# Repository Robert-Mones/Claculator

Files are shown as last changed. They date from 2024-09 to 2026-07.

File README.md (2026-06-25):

# Claculator
A reverse Polish notation calculator with added features such as comparisons, branching, and custom recursive operators taken from the Clac project from the 15-122 course at Carnegie Mellon University. The project is built around a 65C02 microprocessor with a custom architecture to reduce CPU load by making memory-mapped peripherals operate asynchronously. All logic and board design was done in KiCAD. All 3D modeling was done in Autodesk Fusion.

<p align="center">Fully assembled Claculator</p>

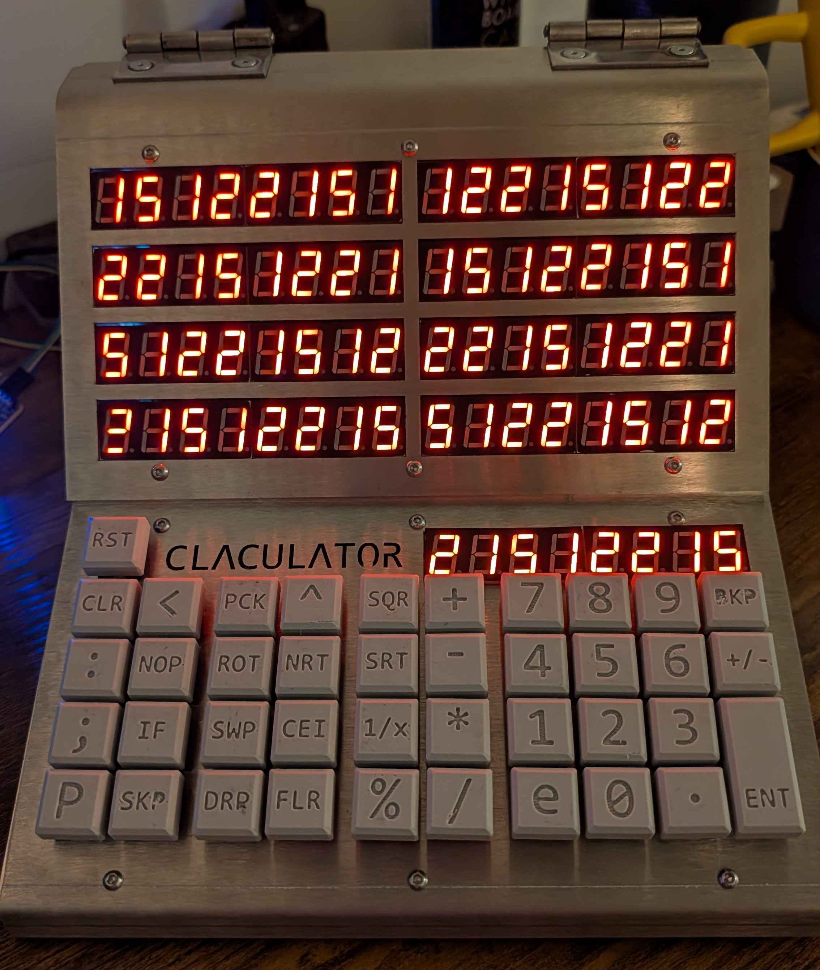
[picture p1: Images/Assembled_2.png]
Fully assembled Claculator


## Display
The seven-segment display board supports nine numeric displays, each with eight digits. It contains an SRAM chip which interfaces to the rest of the computer as a memory-mapped peripheral. When selected, the address and data bus is connected to the computer to be written to (but not read from) transparently. When the memory is not selected, a counter with a selectable clock source loops through each of the seventy-two digits, reads the corresponding byte from memory, and drives the corresponding digit using one bit for each segement (seven for the numeric part, one for the decimal point) with an array of P- and N-channel MOSFETs.

<p align="center">The front of the display, showing eight numeric displays</p>

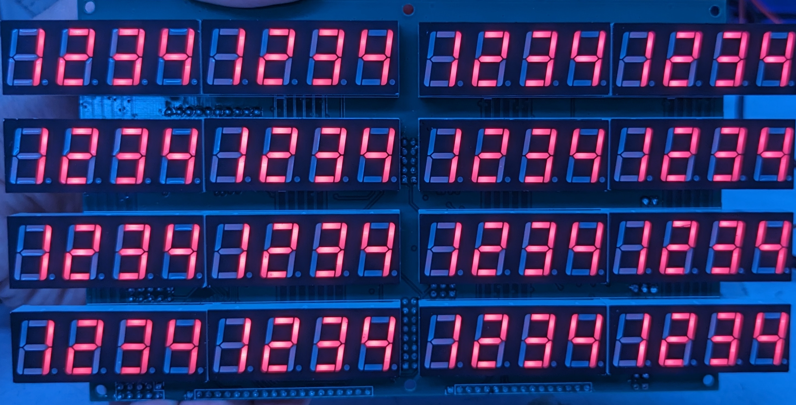
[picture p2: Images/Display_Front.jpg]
The front of the display, showing eight numeric displays


<p align="center">The back of the display, showing the logic and driver chips</p>

The back of the display, showing the logic and driver chips

## Keypad
The keypad input board supports up to sixteen rows (5 are implemented), each with eight buttons. It detects rising edges of each button (equivalent to KeyDown events) with hardware RC debouncing and writes this information to a hardware FIFO buffer which is interfaced directly to the address and data bus of the system and can be configured to send an interrupt on new information in the buffer. It also has a header and location for a seven-segment display (not populated in these photos) as the ninth display that is driven from the display board.

<p align="center">The front of the keypad, showing five groups of eight keys</p>

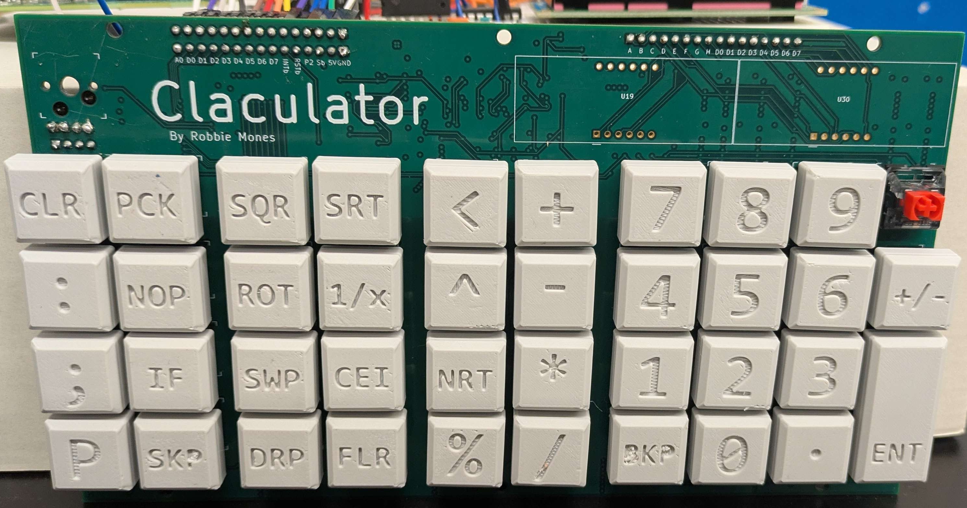
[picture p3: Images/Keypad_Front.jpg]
The front of the keypad, showing five groups of eight keys


<p align="center">The back of the keypad, showing the logic chips and hot-swappable key sockets</p>

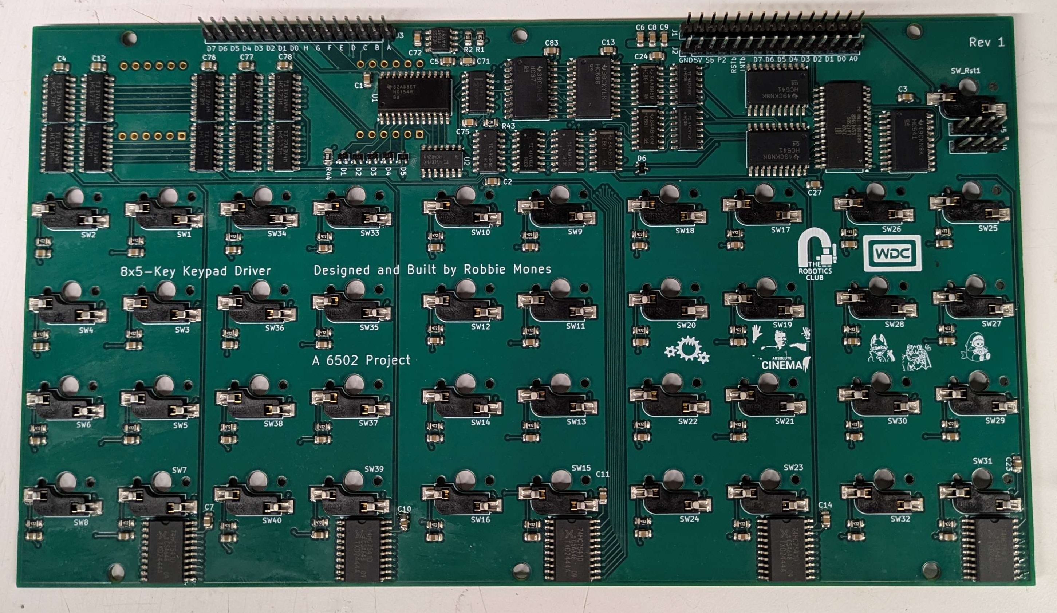
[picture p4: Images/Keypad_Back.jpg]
The back of the keypad, showing the logic chips and hot-swappable key sockets


## Chassis
The chassis for the Claculator was manufactured by SendCutSend out of 1/8"-thick 304 stainless steel (except for the keypad plate which must be 0.06" thick to fit the keys). It has hinges at the top back to open the Claculator from the front to enable demonstrations and debugging more easily. It is very heavy (8lbs of sheet metal) and was very expensive but it's worth it for the bit.

<p align="center">Model of the assembled Claculator</p>

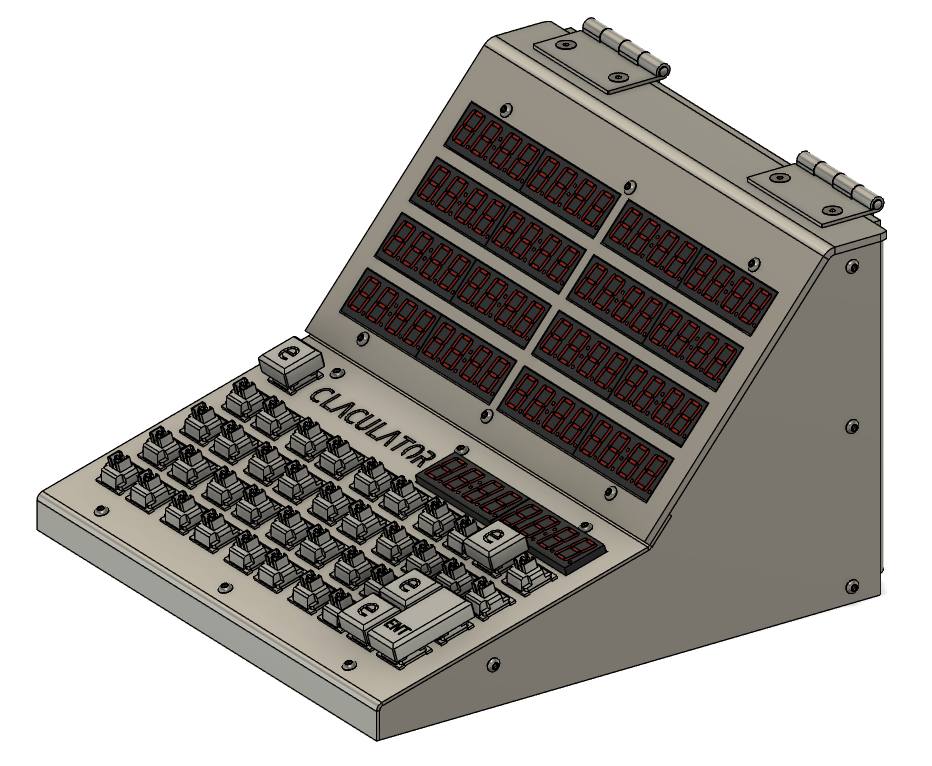
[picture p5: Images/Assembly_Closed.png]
Model of the assembled Claculator


## Code
I am currently working on some tests building up to a 32-bit integer mode to develop the RPN behavior and a feature-complete Clac implementation. After this, I will write a software 32-bit floating point implementation to support decimal arithmetic and comparisons. All of the code for this project will be written in 65C02 assembly.

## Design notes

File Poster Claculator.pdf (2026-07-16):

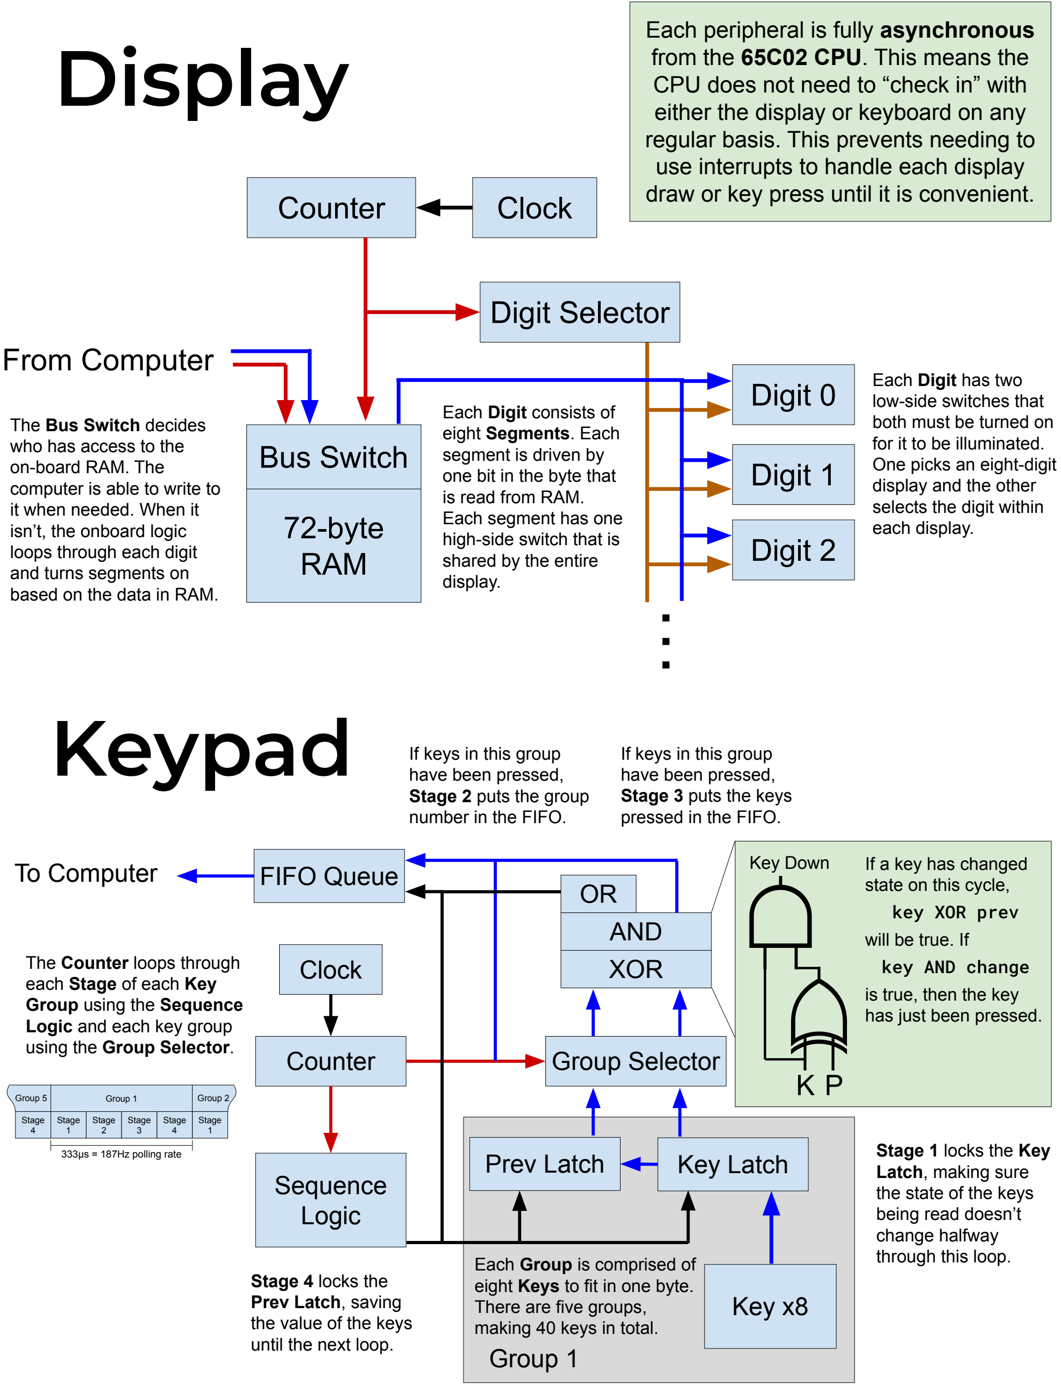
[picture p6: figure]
Display; Keypad; 72-byte RAM; Counter; Digit 0; Digit 1; Digit 2; Digit Selector; From Computer; Bus Switch; Clock; The Bus Switch decides who has access to the on-board RAM. The computer is able to write to it when needed. When it isn’t, the onboard logic loops through each digit and turns segments on based on the data in RAM.; Each Digit consists of eight Segments. Each segment is driven by one bit in the byte that is read from RAM. Each segment has one high-side switch that is shared by the entire display.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

…

draw or key press until it is convenient.

https://github.com/Robert-Mones/Claculator

## Group 2

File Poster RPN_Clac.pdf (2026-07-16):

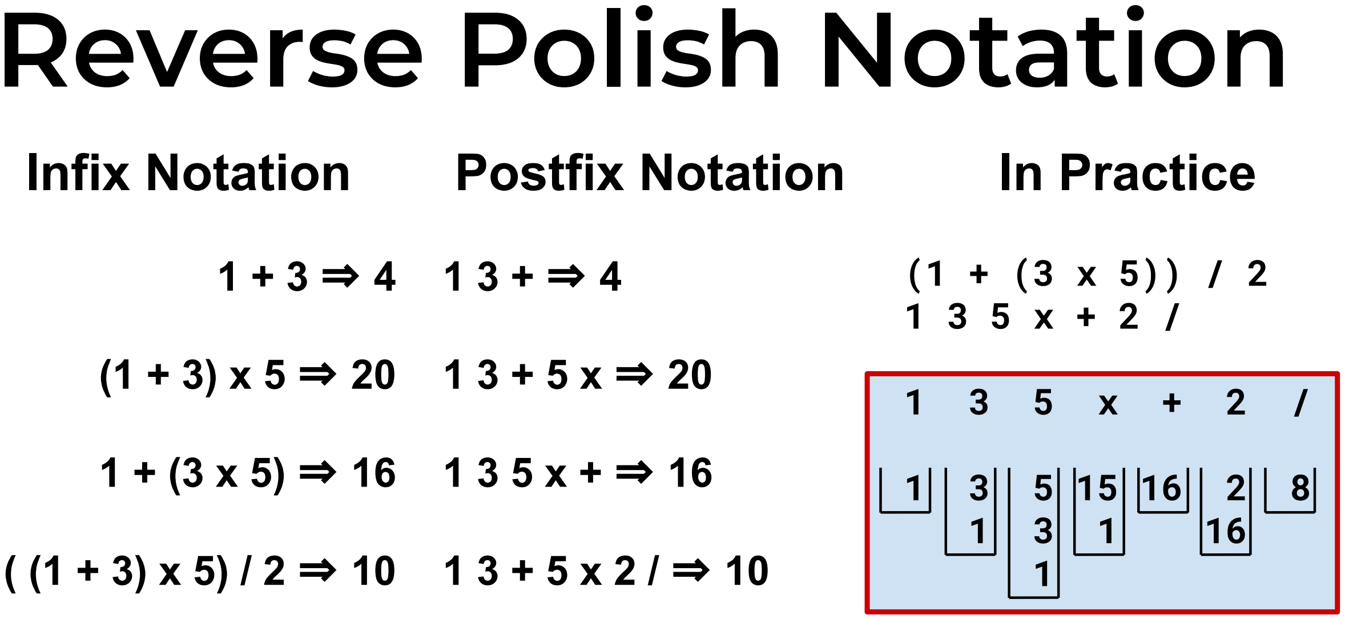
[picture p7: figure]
Reverse Polish Notation; Infix Notation; Postfix Notation; In Practice

Operators take the top two elements off of the stack, operate on them, and put
the result back on the stack.

Reverse Polish Notation uses a Stack to process each expression left-to-right.

Each symbol is either an operand (number) or an operator (+, -, x, etc).

Operands are pushed to the stack.

# Clac

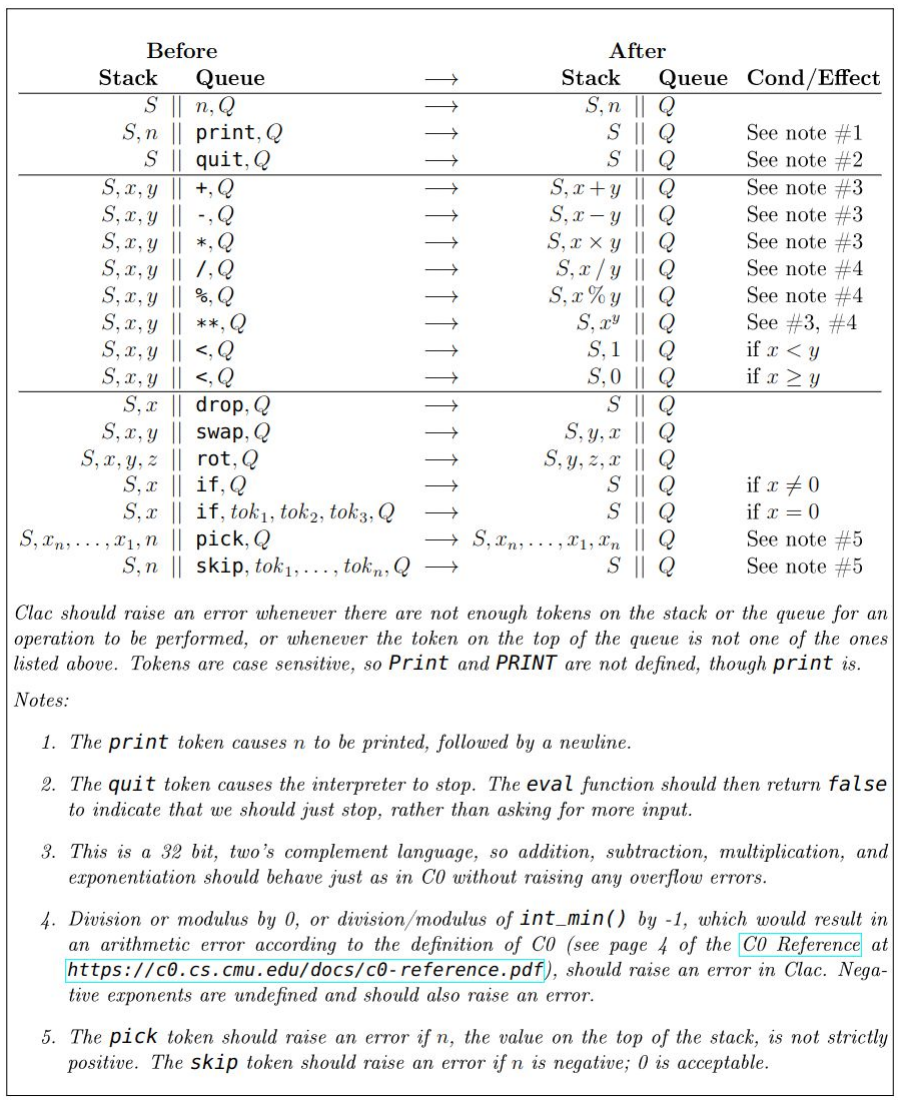
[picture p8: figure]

Complete Clac reference reproduced with permission
Clac is an extension to RPN similar to the Forth programming language which adds additional operators like if and skip, as well as custom operators which can be recursive.
This allows “programs” to be written in Clac which are able to perform complex mathematical calculations. It’s actually Turing-complete!

The following implements a Fibonacci using the Clac operators. : fib dup 2 < if nop 9 skip 1 - dup 1 - fib swap fib + ;

Pseudocode:
fib(x):
if x < 2:
return x
return fib(x-2) + fib(x-1)

1 3 +

1 | 3 | 4
| 1

# No parentheses!

# Easy to evaluate!

# Turing-complete*!

*Clac extension sold separately

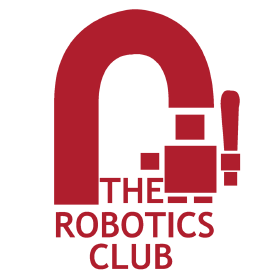
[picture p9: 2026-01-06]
Claculator_Keypad/Imagery/Roboclub.png

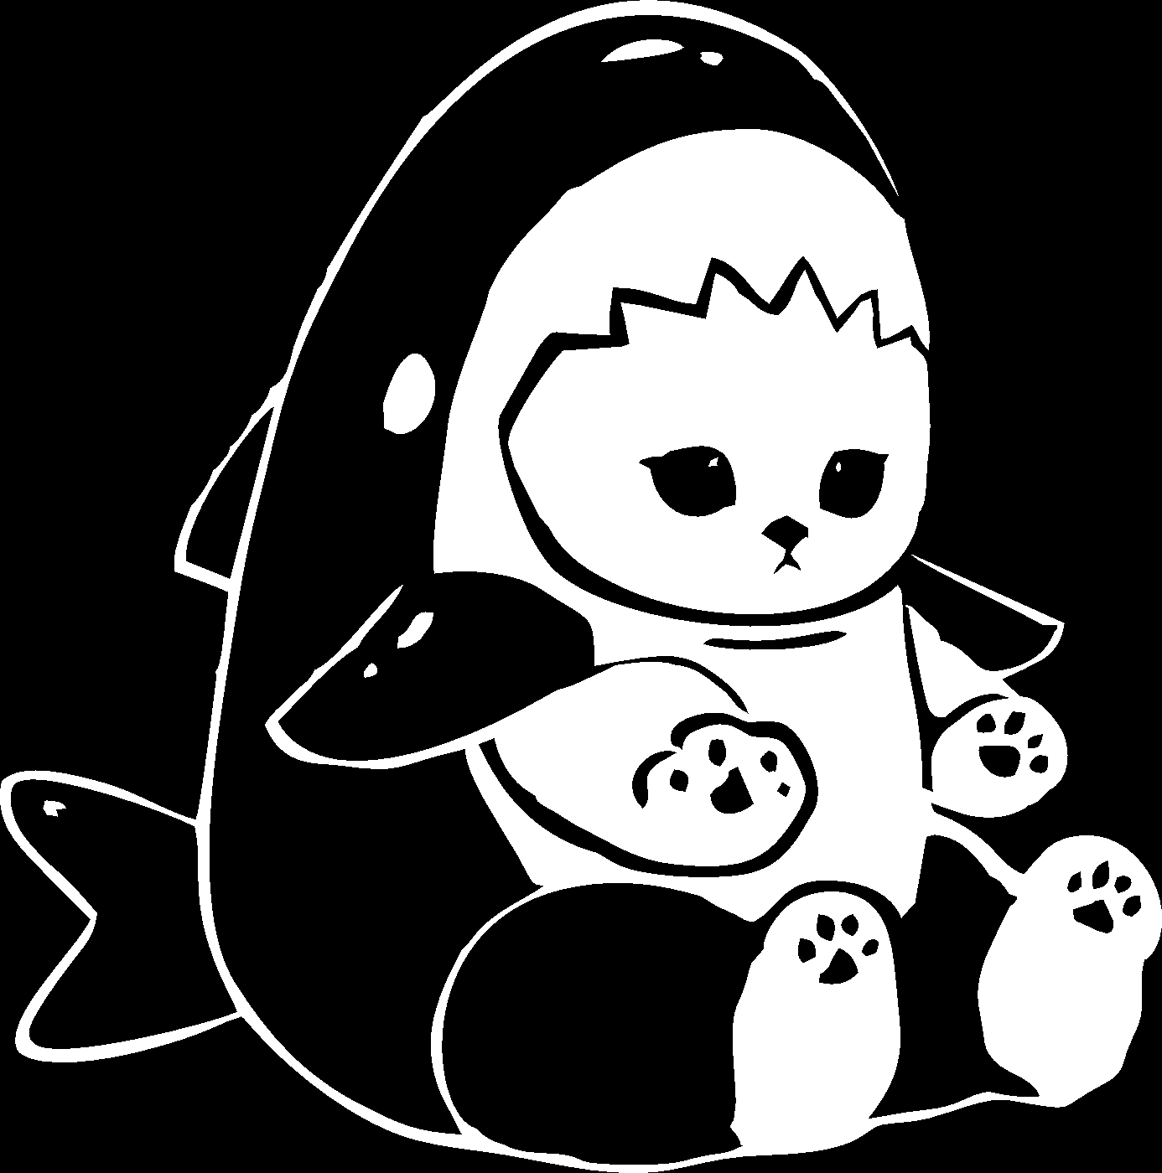
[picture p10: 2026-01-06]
Claculator_Display/Imagery/bnyahaj.png

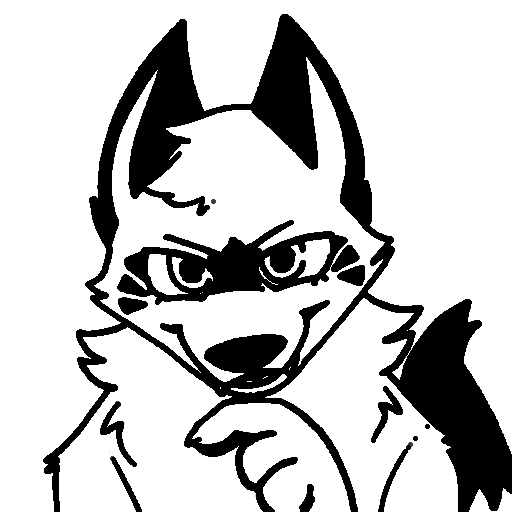
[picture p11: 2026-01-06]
Claculator_Keypad/Imagery/salixplotting-thick.png

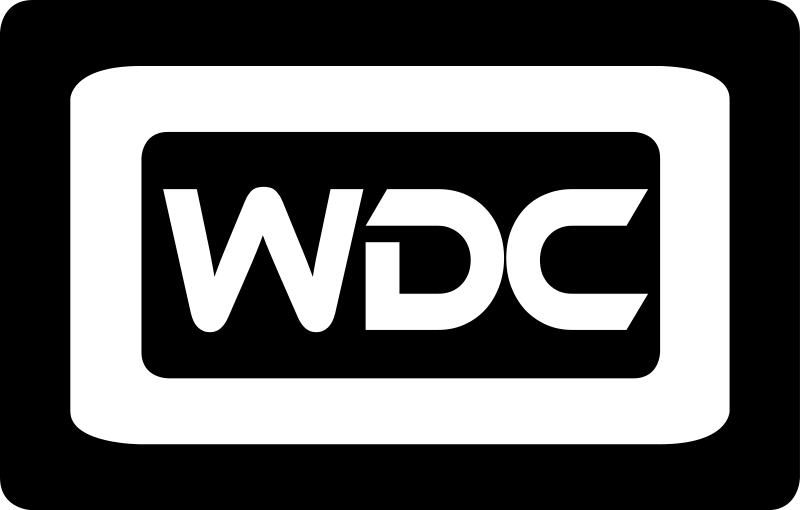
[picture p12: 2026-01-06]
Claculator_Keypad/Imagery/WDC.png

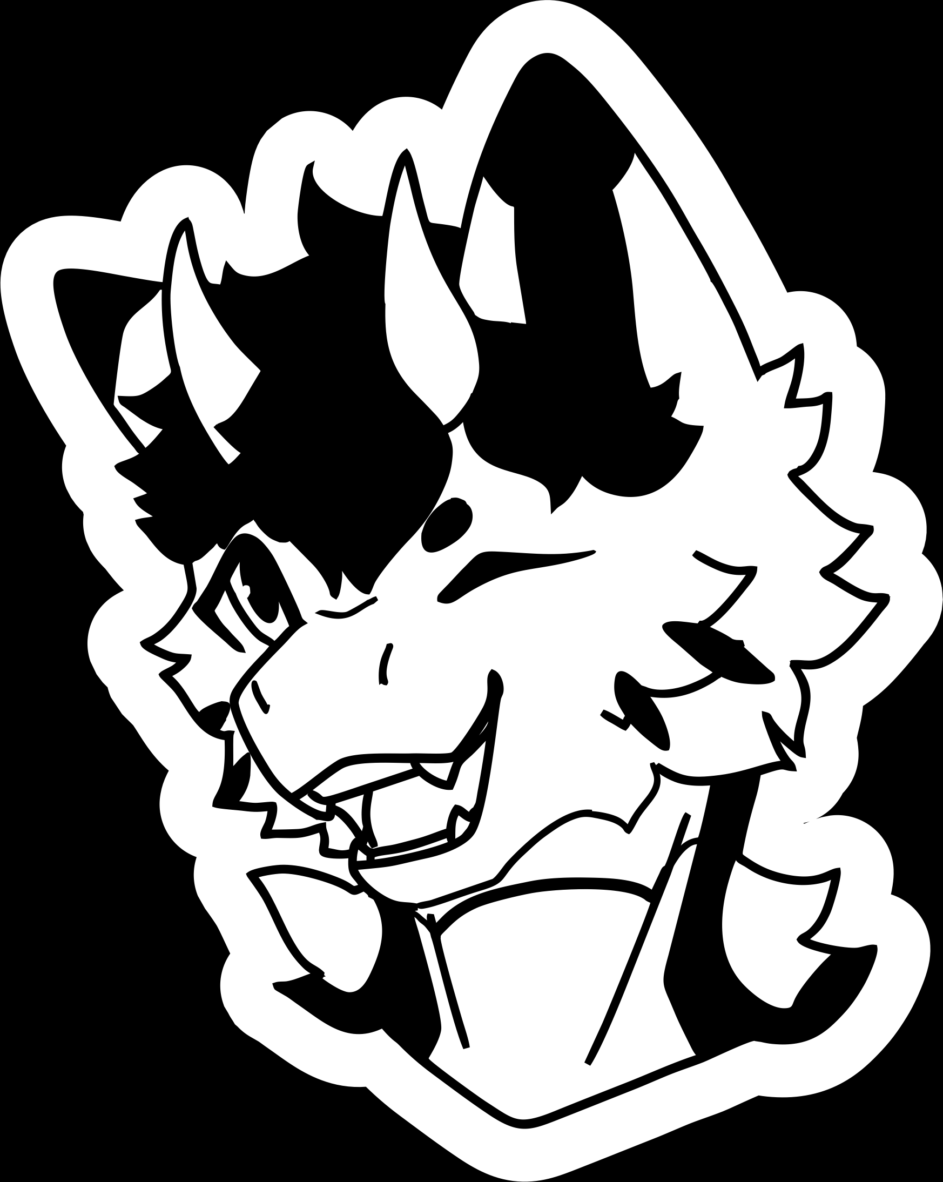
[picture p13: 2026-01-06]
Claculator_Display/Imagery/sky.png

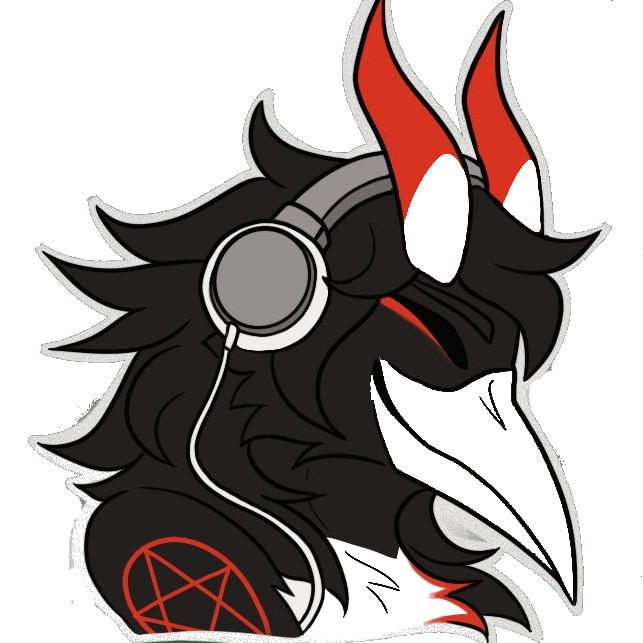
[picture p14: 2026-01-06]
Claculator_Display/Imagery/dante.png

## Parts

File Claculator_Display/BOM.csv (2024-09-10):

Reference | Value | Datasheet | Footprint | Qty | DNP
C1,C4 | 10uF | ~ | Capacitor_SMD:C_1206_3216Metric | 2
C2,C5,C7,C8,C9,C10,C11,C12,C13,C14,C15,C16,C17,C18,C19,C20,C21,C22,C23 | 1uF | ~ | Capacitor_SMD:C_1206_3216Metric | 19
C3,C6 | 0.1uF | ~ | Capacitor_SMD:C_1206_3216Metric | 2
C24,C25 | 100uF | ~ | Capacitor_SMD:CP_Elec_5x3 | 2
J1,U14,U15,U16,U17,U34,U35,U36 | ~ |  | -- mixed values -- | 8
J4 | Conn_01x20_Pin | ~ | Connector_PinHeader_2.54mm:PinHeader_1x20_P2.54mm_Vertical | 1
J5 | Power Input | ~ | Connector:JWT_A3963_1x02_P3.96mm_Vertical | 1
J6 | Conn_01x16_Pin | ~ | Connector_PinHeader_2.54mm:PinHeader_1x16_P2.54mm_Vertical | 1
Q1,Q2,Q3,Q4,Q5,Q6,Q7,Q8 | PMOS | https://ngspice.sourceforge.io/docs/ngspice-manual.pdf | Custom_Library:SOT-23P | 8
Q9,Q10,Q11,Q12,Q13,Q14,Q15,Q16,Q17,Q18,Q19,Q20,Q21,Q22,Q23,Q24,Q25,Q26,Q27,Q28,Q29,Q30,Q31,Q32,Q33,Q34,Q35,Q36,Q37,Q38,Q39,Q40,Q41,Q42,Q43,Q44,Q45,Q46,Q47,Q48,Q49,Q50,Q51,Q52,Q53,Q54,Q55,Q56,Q57,Q58,Q59,Q60,Q61,Q62,Q63,Q64,Q65,Q66,Q67,Q68,Q69,Q70,Q71,Q72,Q73,Q74,Q75,Q76,Q77,Q78,Q79,Q80,Q81,Q82,Q83,Q84,Q85,Q86,Q87,Q88,Q89 | NMOS | https://ngspice.sourceforge.io/docs/ngspice-manual.pdf | Custom_Library:SOT-23N | 81
R1 | 10K | ~ | Resistor_SMD:R_1206_3216Metric | 1
U1,U2,U6 | 74HC541 | http://www.ti.com/lit/gpn/sn74HCT541 | Package_SO:SOIC-20W_7.5x12.8mm_P1.27mm | 3
U3 | 74HC14 | http://www.ti.com/lit/gpn/sn74HC14 | Package_SO:SOIC-14_3.9x8.7mm_P1.27mm | 1
U4 | 74HC00 | http://www.ti.com/lit/gpn/sn74hc00 | Package_SO:SOIC-14_3.9x8.7mm_P1.27mm | 1
U5 | IS62C256AL | https://www.futurlec.com/Datasheet/Memory/62256.pdf | IS62C256AL_45ULI_TR:SOIC127P1210X305-28N | 1
U7 | 74HC4020 | http://www.intersil.com/content/dam/Intersil/documents/cd40/cd4020bms-24bms-40bms.pdf | Package_SO:SOIC-16_3.9x9.9mm_P1.27mm | 1
U8 | 74HC4024 | https://assets.nexperia.com/documents/data-sheet/74HC4024.pdf | Package_SO:SOIC-14_3.9x8.7mm_P1.27mm | 1
U9,U10 | 74HC154 |  | Package_SO:SOIC-24W_7.5x15.4mm_P1.27mm | 2
U11 | LD1086V33-DG | https://www.st.com/resource/en/datasheet/ld1086.pdf | Package_TO_SOT_THT:TO-220-3_Vertical | 1
U12,U13,U18,U19,U20,U21,U22,U23,U24,U25,U26,U27,U28,U29,U30,U31 | CC56-12EWA | http://www.kingbrightusa.com/images/catalog/SPEC/CA56-12EWA.pdf | Display_7Segment:CA56-12EWA | 16

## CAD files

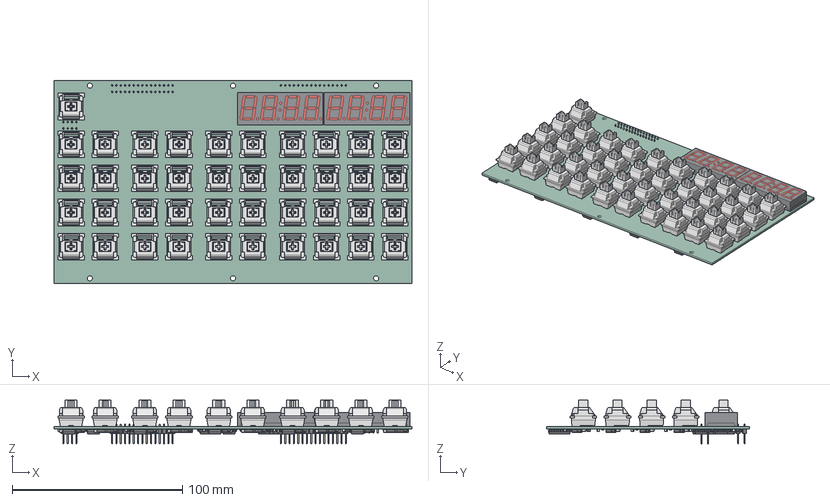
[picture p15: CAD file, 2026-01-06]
Claculator_Keypad/Claculator_Keypad.step
210.0 x 119.0 x 25.5 mm
REDragon-MX-ZT02 x 41
Kailh Hotswap MX v22 x 41
Body_sp x 2
C_0805_2012Metric x 64
R_0805_2012Metric x 44
SOIC_16_39x99mm_P127mm x 10
SOT_323_SC_70 x 6
SOIC_20W_75x128mm_P127mm x 10
SOIC_14_39x87mm_P127mm x 10
PinHeader_1x16_P254mm_Vertical
SOIC_28W_75x187mm_P127mm
SOIC_8_39x49mm_P127mm
SOIC_24W_75x154mm_P127mm
PinHeader_1x04_P254mm_Vertical x 2
PinHeader_1x15_P254mm_Vertical x 2
Claculator_Keypad_PCB

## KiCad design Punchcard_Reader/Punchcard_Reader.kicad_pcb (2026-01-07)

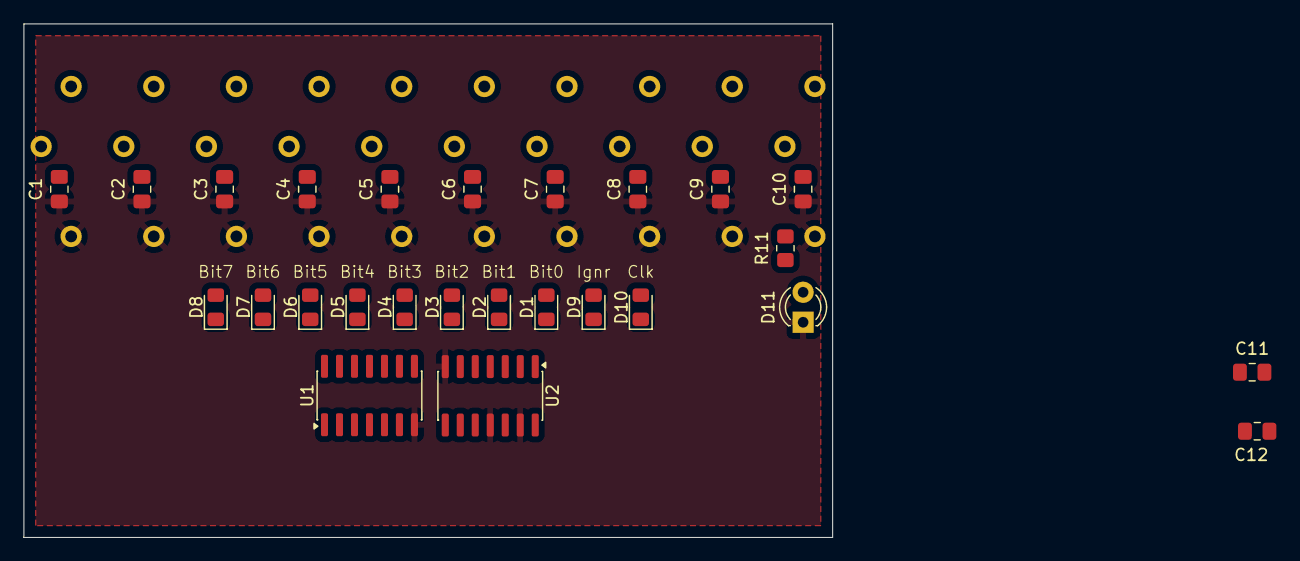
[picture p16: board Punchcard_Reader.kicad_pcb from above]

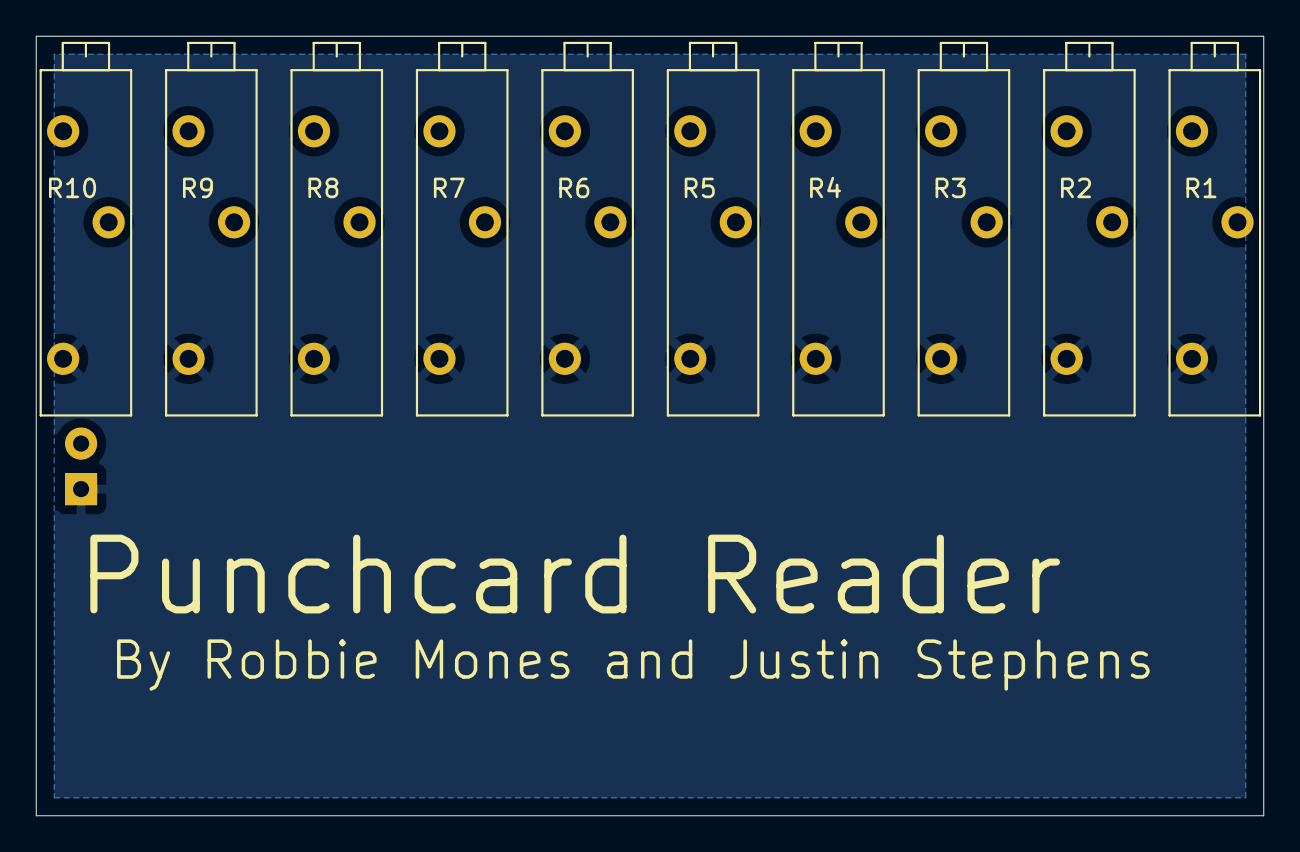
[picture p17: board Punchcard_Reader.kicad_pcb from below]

Board: 4 copper layers, 68.5 x 43.5 mm, 36 parts (10 on the bottom side), 13 nets, no tracks yet.

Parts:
C1, C2, C3, C4, C5, C6, C7, C8, C9, C10: 470pF; C_0805_2012Metric_Pad1.18x1.45mm_HandSolder
C11, C12: 0.1uF; C_0805_2012Metric_Pad1.18x1.45mm_HandSolder
D1, D2, D3, D4, D5, D6, D7, D8, D9, D10: APS2012SP1C; LED_0805_2012Metric_Pad1.15x1.40mm_HandSolder
D11: LED_BACKLIGHT; LED_D3.0mm
R1, R2, R3, R4, R5, R6, R7, R8, R9, R10: 500k; VariableResistor_Bourns_3006P_Horizontal_
R11: 120Ω; R_0805_2012Metric_Pad1.20x1.40mm_HandSolder
U1, U2: 74HC14; SOIC-14_3.9x8.7mm_P1.27mm

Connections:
+5V: C11.1, C12.1, D1.1 (K), D2.1 (K), D3.1 (K), D4.1 (K), D5.1 (K), D6.1 (K), D7.1 (K), D8.1 (K), D9.1 (K), D10.1 (K), R11.1, U1.14 (VCC), U2.14 (VCC)
GND: C1.2, C2.2, C3.2, C4.2, C5.2, C6.2, C7.2, C8.2, C9.2, C10.2, C11.2, C12.2, D11.1 (K), R1.1, R2.1, R3.1, R4.1, R5.1, R6.1, R7.1, R8.1, R9.1, R10.1, U1.7 (GND), U2.7 (GND), U2.11, U2.13
unnamed: C1.1, D1.2 (A), R1.2, U1.1
unnamed: C2.1, D2.2 (A), R2.2, U1.3
unnamed: C3.1, D3.2 (A), R3.2, U1.5
unnamed: C4.1, D4.2 (A), R4.2, U1.9
unnamed: C5.1, D5.2 (A), R5.2, U1.11
unnamed: C6.1, D6.2 (A), R6.2, U1.13
unnamed: C7.1, D7.2 (A), R7.2, U2.1
unnamed: C8.1, D8.2 (A), R8.2, U2.3
unnamed: C9.1, D9.2 (A), R9.2, U2.5
unnamed: C10.1, D10.2 (A), R10.2, U2.9
unnamed: D11.2 (A), R11.2

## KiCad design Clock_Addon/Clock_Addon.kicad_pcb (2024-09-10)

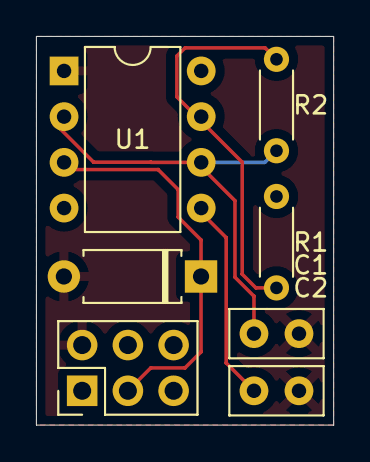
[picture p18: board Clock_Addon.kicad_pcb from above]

Board: 6 copper layers, 16.5 x 21.6 mm, 7 parts (0 on the bottom side), 6 nets.

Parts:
C1, C2: C; C_Disc_D5.0mm_W2.5mm_P2.50mm
D1: D_Zener; D_A-405_P7.62mm_Horizontal
J2: Conn_01x06_Pin; PinHeader_2x03_P2.54mm_Vertical
R1, R2: R; R_Axial_DIN0204_L3.6mm_D1.6mm_P5.08mm_Horizontal
U1: NE555P; DIP-8_W7.62mm

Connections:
+5V: J2.1, R1.1, U1.4 (R), U1.8 (VCC)
CNTR_CLK: D1.1 (K), J2.3, U1.3 (Q)
GND: C1.2, C2.1, D1.2 (A), J2.2, U1.1 (GND)
unnamed: C2.2, U1.5 (CV)
unnamed: R1.2, R2.1, U1.7 (DIS)
unnamed: C1.1, R2.2, U1.2 (TR), U1.6 (THR)

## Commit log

2024-09-10 Added existing KiCAD projects
    [BOM.csv, BOM_Final.csv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]
2026-01-06 Added kicad backups to gitignore
2026-01-06 Added Clock_Addon kicad backups to gitignore
2026-01-06 Not sure
    [Claculator_Keypad-B_Cu.gbl, Claculator_Keypad-B_Mask.gbs, Claculator_Keypad-B_Paste.gbp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]
2026-01-06 Added Punchcard_Reader kicad backups and lock files to gitignore
2026-01-06 Punchcard_Reader init commit
    [Punchcard_Reader.kicad_pcb, Punchcard_Reader.kicad_sch]
2026-01-07 Added initial parts
    [Punchcard_Reader.kicad_pcb, Punchcard_Reader.kicad_sch, filtered_photodiode.kicad_sch]
2026-03-24 Added debugger submodule and current code
2026-06-25 Added image of fully assembled Claculator
2026-07-17 Added auto push to stack and some key filtering
